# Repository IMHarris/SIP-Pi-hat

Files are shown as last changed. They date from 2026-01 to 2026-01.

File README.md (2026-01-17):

# SIP Pi HAT

Raspberry Pi HAT for the [SIP (Smart Irrigation Program)](https://github.com/Dan-in-CA/SIP) irrigation controller.

## Features

- Designed to interface with SIP irrigation controller on Raspberry Pi
- Outputs for relay control of up to 16 stations with 74HC595 output header for more
- XAIO ESP32C3 module for flow sensor monitoring with inputs for hall flow sensor. Designed to work with the flow plugin
- Communicates flow sensor data to Pi via UART
- 5v I2c headers. Great for LCD plugin.

## Hardware

This project contains KiCad 7+ design files:
- `SIP_Hat.kicad_sch` - Schematic
- `SIP_Hat.kicad_pcb` - PCB layout
- `SIP_Hat.kicad_pro` - Project file
- `Gerber/` - Manufacturing files

## Firmware

The ESP32C3 firmware is available in the companion repository: [flow-sensor-esp32](https://github.com/IMHarris/flow-sensor-esp32)

## Bill of Materials

See `SIP_Hat.csv` for the complete BOM.

## Related Projects

- [SIP Irrigation Controller](https://github.com/Dan-in-CA/SIP)
- [SIP Plugins](https://github.com/Dan-in-CA/sip_plugins)
- [ESP32C3 Flow Sensor Firmware](https://github.com/IMHarris/flow-sensor-esp32)

## License

This hardware design is licensed under [CC BY-SA 4.0](http://creativecommons.org/licenses/by-sa/4.0/).

You are free to share and adapt this work, provided you give appropriate credit and distribute your contributions under the same license.

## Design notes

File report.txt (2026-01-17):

Plotted to '/Users/ianharris/Tech Projects/KiCad SPI Hat/SIP_Hat/Gerber/SIP_Hat-F_Cu.gbr'.
Plotted to '/Users/ianharris/Tech Projects/KiCad SPI Hat/SIP_Hat/Gerber/SIP_Hat-B_Cu.gbr'.
Plotted to '/Users/ianharris/Tech Projects/KiCad SPI Hat/SIP_Hat/Gerber/SIP_Hat-F_Paste.gbr'.
Plotted to '/Users/ianharris/Tech Projects/KiCad SPI Hat/SIP_Hat/Gerber/SIP_Hat-B_Paste.gbr'.
Plotted to '/Users/ianharris/Tech Projects/KiCad SPI Hat/SIP_Hat/Gerber/SIP_Hat-F_Silkscreen.gbr'.
Plotted to '/Users/ianharris/Tech Projects/KiCad SPI Hat/SIP_Hat/Gerber/SIP_Hat-B_Silkscreen.gbr'.
Plotted to '/Users/ianharris/Tech Projects/KiCad SPI Hat/SIP_Hat/Gerber/SIP_Hat-F_Mask.gbr'.
Plotted to '/Users/ianharris/Tech Projects/KiCad SPI Hat/SIP_Hat/Gerber/SIP_Hat-B_Mask.gbr'.
Plotted to '/Users/ianharris/Tech Projects/KiCad SPI Hat/SIP_Hat/Gerber/SIP_Hat-Edge_Cuts.gbr'.
Created Gerber job file '/Users/ianharris/Tech Projects/KiCad SPI Hat/SIP_Hat/Gerber/SIP_Hat-job.gbrjob'.
Info: Done.
Info: Done.

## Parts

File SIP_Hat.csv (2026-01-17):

Reference | Qty | Value | DNP | Exclude from BOM | Exclude from Board | Footprint | Datasheet
5v_in1 | 1 | 10164359-00011LF |  |  |  | 10164359-00011LF:AMPHENOL_10164359-00011LF
C1,C2,C7 | 3 | 0.1µF |  |  |  | Capacitor_SMD:C_0805_2012Metric_Pad1.18x1.45mm_HandSolder | ~
C5,C6,C27 | 3 | 10µF |  |  |  | Capacitor_SMD:C_1206_3216Metric_Pad1.33x1.80mm_HandSolder | https://www.digikey.com/en/products/detail/samsung-electro-mechanics/CL21A106KPFNNNE/3886710,~
D1,D2 | 2 | LED |  |  |  | PCM_LED_SMD_Handsoldering_AKL:LED_1206_3216Metric_Pad1.42x1.75mm | ~
H1,H2,H3,H4 | 4 | MountingHole |  | Excluded from BOM |  | MountingHole:MountingHole_2.7mm_M2.5_ISO14580 | ~
J1 | 1 | Raspberry Pi Header |  |  |  | Connector_PinHeader_2.54mm:PinHeader_2x20_P2.54mm_Vertical | ~
J2 | 1 | Relay terminal 1 |  |  |  | Ians_Parts:PHOENIX_1990083 | ~
J3 | 1 | Relay terminal 2 |  |  |  | Ians_Parts:PHOENIX_1990083 | ~
J4 | 1 | I2C 5V 1 |  |  |  | Connector_PinHeader_2.54mm:PinHeader_1x04_P2.54mm_Vertical | ~
J5 | 1 | I2C 5V 2 |  |  |  | Connector_PinHeader_2.54mm:PinHeader_1x04_P2.54mm_Vertical | ~
J6 | 1 | To Flow Sensor |  |  |  | Ians_Parts:PHOENIX_1729131 | ~
J7 | 1 | Conn_01x06_Pin |  |  |  | Connector_PinHeader_2.54mm:PinHeader_1x06_P2.54mm_Vertical | ~
J22 | 1 | Relay terminal 1 |  |  |  | Connector_Molex:Molex_SL_171971-0010_1x10_P2.54mm_Vertical | ~
J23 | 1 | Relay terminal 2 |  |  |  | Connector_Molex:Molex_SL_171971-0010_1x10_P2.54mm_Vertical | ~
Q1,Q2 | 2 | BSS138 |  |  |  | PCM_Package_TO_SOT_SMD_AKL:SOT-23 | https://www.tme.eu/Document/2b32cdd3c66afedbcd628e73d93ae817/BSS138-7-F.pdf
R1,R9,R10,R11,R12 | 5 | 10k |  |  |  | Resistor_SMD:R_1206_3216Metric_Pad1.30x1.75mm_HandSolder | ~
R3 | 1 | 1.5k |  |  |  | Resistor_SMD:R_1206_3216Metric_Pad1.30x1.75mm_HandSolder | ~
R4,R5 | 2 | 5.1k |  |  |  | Resistor_SMD:R_1206_3216Metric_Pad1.30x1.75mm_HandSolder | ~
R6 | 1 | 470 |  |  |  | Resistor_SMD:R_1206_3216Metric_Pad1.30x1.75mm_HandSolder | ~
SW1 | 1 | SW_Slide_DPDT |  |  |  | Ians_Parts:DPDT Slide switch - CL-SB-22C-02 | ~
U1,U2 | 2 | 74HC595 |  |  |  | Package_DIP:DIP-16_W7.62mm_Socket | http://www.ti.com/lit/ds/symlink/sn74hc595.pdf
U3 | 1 | 113991054 |  |  |  | 113991054:MODULE_113991054 | https://mm.digikey.com/Volume0/opasdata/d220001/medias/docus/6209/Seeed%20113991054.pdf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..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

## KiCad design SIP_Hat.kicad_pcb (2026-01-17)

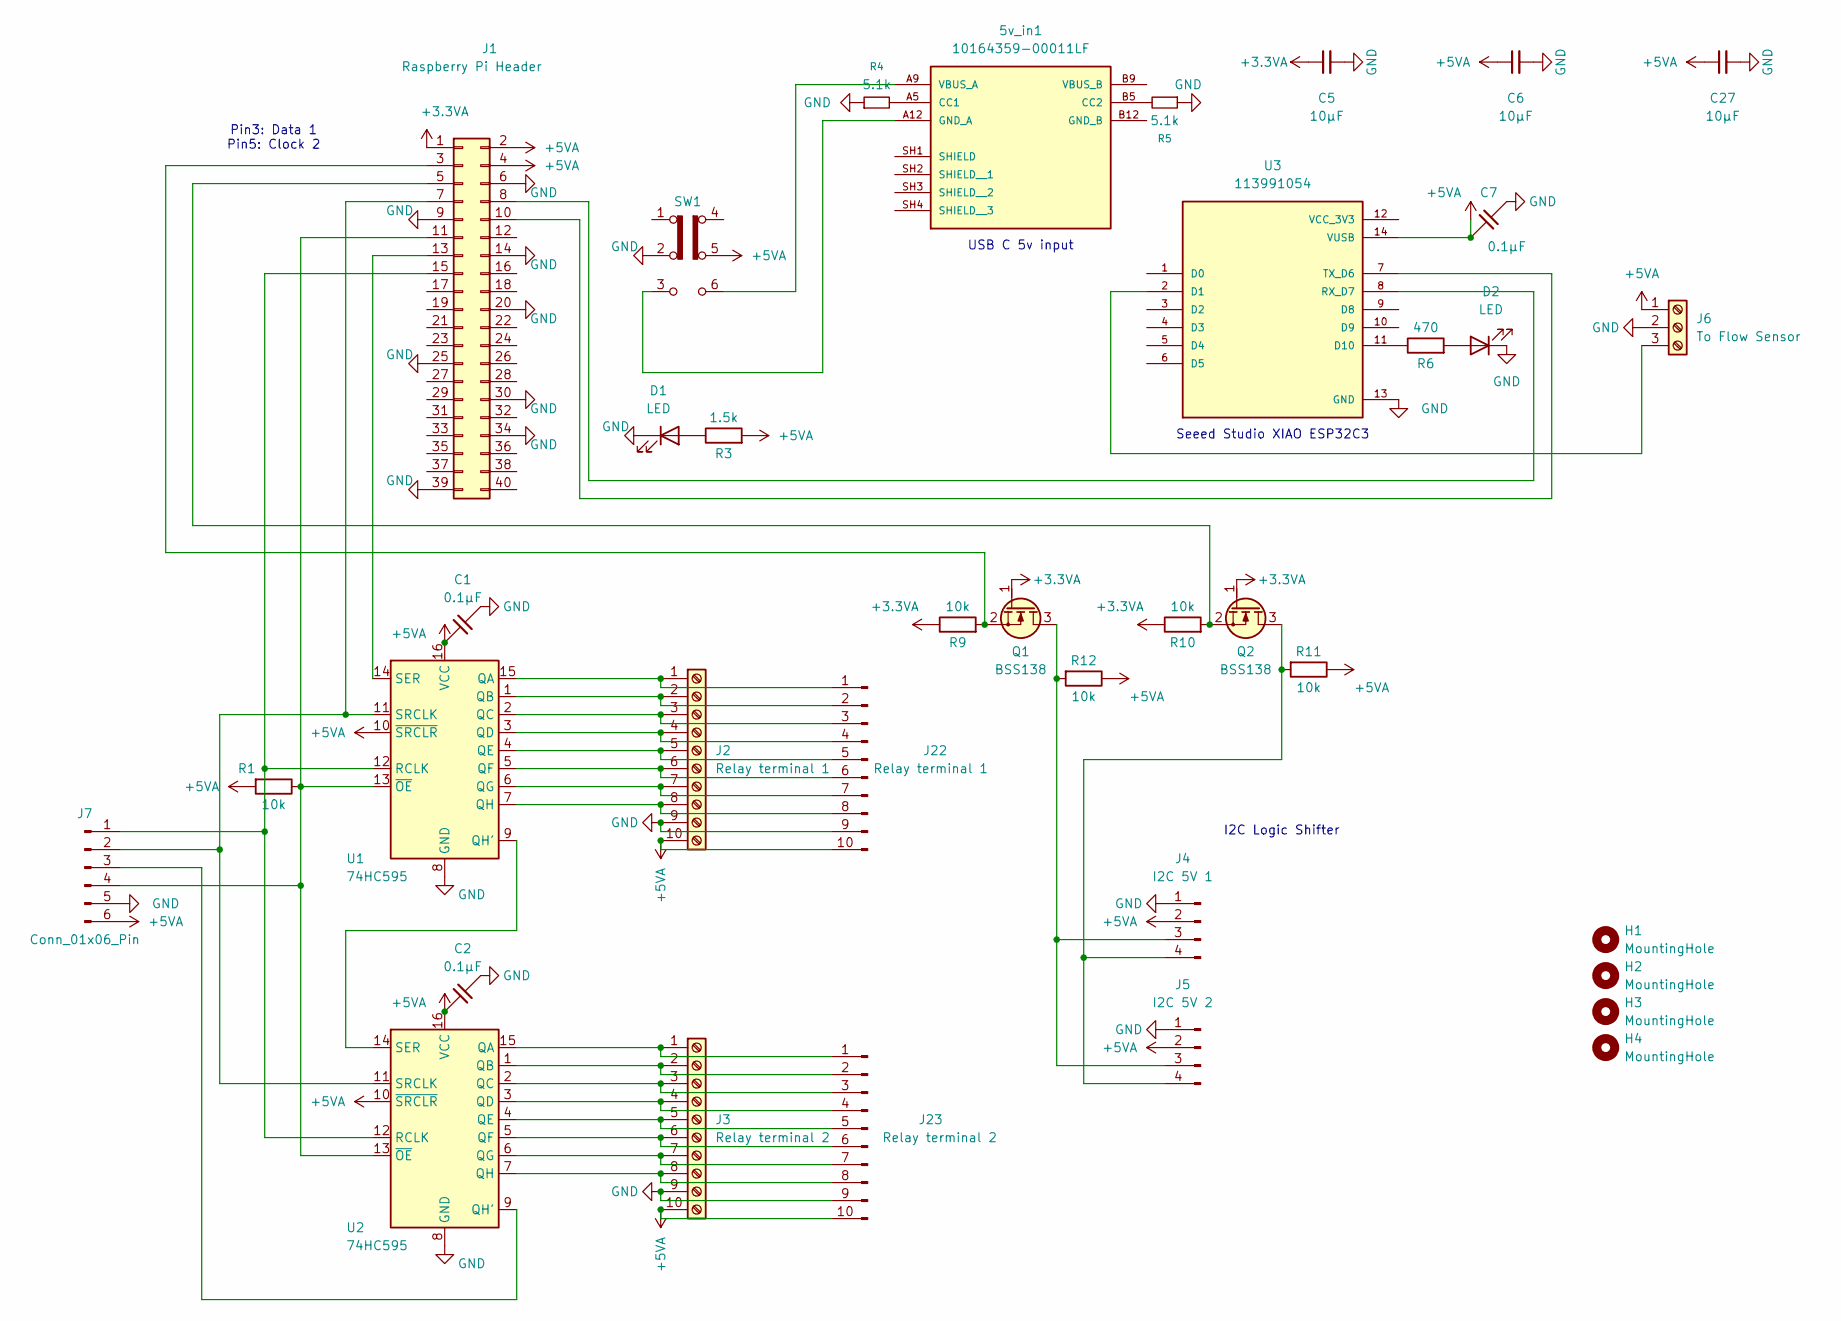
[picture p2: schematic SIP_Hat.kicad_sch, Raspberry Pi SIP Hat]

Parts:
5v_in1: 10164359-00011LF; AMPHENOL_10164359-00011LF; PARTREV A
C1, C2, C7: 0.1µF; C_0805_2012Metric_Pad1.18x1.45mm_HandSolder
C5, C6, C27: 10µF; C_1206_3216Metric_Pad1.33x1.80mm_HandSolder
D1, D2: LED; LED_1206_3216Metric_Pad1.42x1.75mm
H1, H2, H3, H4: MountingHole; MountingHole_2.7mm_M2.5_ISO14580
J1: Raspberry Pi Header; PinHeader_2x20_P2.54mm_Vertical
J2: Relay terminal 1; PHOENIX_1990083
J3: Relay terminal 2; PHOENIX_1990083
J4: I2C 5V 1; PinHeader_1x04_P2.54mm_Vertical
J5: I2C 5V 2; PinHeader_1x04_P2.54mm_Vertical
J6: To Flow Sensor; PHOENIX_1729131
J7: Conn_01x06_Pin; PinHeader_1x06_P2.54mm_Vertical
J22: Relay terminal 1; Molex_SL_171971-0010_1x10_P2.54mm_Vertical
J23: Relay terminal 2; Molex_SL_171971-0010_1x10_P2.54mm_Vertical
Q1, Q2: BSS138; SOT-23
R1, R9, R10, R11, R12: 10k; R_1206_3216Metric_Pad1.30x1.75mm_HandSolder
R3: 1.5k; R_1206_3216Metric_Pad1.30x1.75mm_HandSolder
R4, R5: 5.1k; R_1206_3216Metric_Pad1.30x1.75mm_HandSolder
R6: 470; R_1206_3216Metric_Pad1.30x1.75mm_HandSolder
SW1: SW_Slide_DPDT; DPDT Slide switch - CL-SB-22C-02
U1, U2: 74HC595; DIP-16_W7.62mm_Socket
U3: 113991054; MODULE_113991054; PARTREV 23/05/2022

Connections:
+3.3VA: C5.1, J1.1, Q1.1 (G), Q2.1 (G), R9.1, R10.1
+5VA: C1.2, C2.2, C6.1, C7.2, C27.1, J1.2, J1.4, J2.10, J3.10, J4.2, J5.2, J6.1, J7.6, J22.10, J23.10, R1.2, R3.2, R11.1, R12.1, SW1.5 (B), U1.10 (~SRCLR), U1.16 (VCC), U2.10 (~SRCLR), U2.16 (VCC), U3.14 (VUSB)
GND: C1.1, C2.1, C5.2, C6.2, C7.1, C27.2, D1.1 (K), D2.1 (K), J1.6, J1.9, J1.14, J1.20, J1.25, J1.30, J1.34, J1.39, J2.9, J3.9, J4.1, J5.1, J6.2, J7.5, J22.9, J23.9, R4.1, R5.1, SW1.2 (B), U1.8 (GND), U2.8 (GND), U3.13 (GND)
unnamed: 5v_in1.A5 (CC1), R4.2
unnamed: 5v_in1.B5 (CC2), R5.2
unnamed: 5v_in1.A12 (GND_A), SW1.3 (C)
unnamed: 5v_in1.A9 (VBUS_A), SW1.6 (A)
unnamed: D1.2 (A), R3.1
unnamed: D2.2 (A), R6.2
unnamed: J1.3, Q1.2 (S), R9.2
unnamed: J1.5, Q2.2 (S), R10.2
unnamed: J1.7, J7.2, U1.11 (SRCLK), U2.11 (SRCLK)
unnamed: J1.8, U3.8 (RX_D7)
unnamed: J1.10, U3.7 (TX_D6)
unnamed: J1.11, J7.4, R1.1, U1.13 (~OE), U2.13 (~OE)
unnamed: J1.13, U1.14 (SER)
unnamed: J1.15, J7.1, U1.12 (RCLK), U2.12 (RCLK)
unnamed: J2.1, J22.1, U1.15 (QA)
unnamed: J2.2, J22.2, U1.1 (QB)
unnamed: J2.3, J22.3, U1.2 (QC)
unnamed: J2.4, J22.4, U1.3 (QD)
unnamed: J2.5, J22.5, U1.4 (QE)
unnamed: J2.6, J22.6, U1.5 (QF)
unnamed: J2.7, J22.7, U1.6 (QG)
unnamed: J2.8, J22.8, U1.7 (QH)
unnamed: J4.3, J5.3, Q1.3 (D), R12.2
unnamed: J4.4, J5.4, Q2.3 (D), R11.2
unnamed: J6.3, U3.2 (D1)
unnamed: J7.3, U2.9 (QH')
unnamed: J3.1, J23.1, U2.15 (QA)
unnamed: J3.2, J23.2, U2.1 (QB)
unnamed: J3.3, J23.3, U2.2 (QC)
unnamed: J3.4, J23.4, U2.3 (QD)
unnamed: J3.5, J23.5, U2.4 (QE)
unnamed: J3.6, J23.6, U2.5 (QF)
unnamed: J3.7, J23.7, U2.6 (QG)
unnamed: J3.8, J23.8, U2.7 (QH)
unnamed: U1.9 (QH'), U2.14 (SER)
unnamed: R6.1, U3.11 (D10)

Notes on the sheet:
USB C 5v input
I2C Logic Shifter
Seeed Studio XIAO ESP32C3
Pin3: Data 1 Pin5: Clock 2

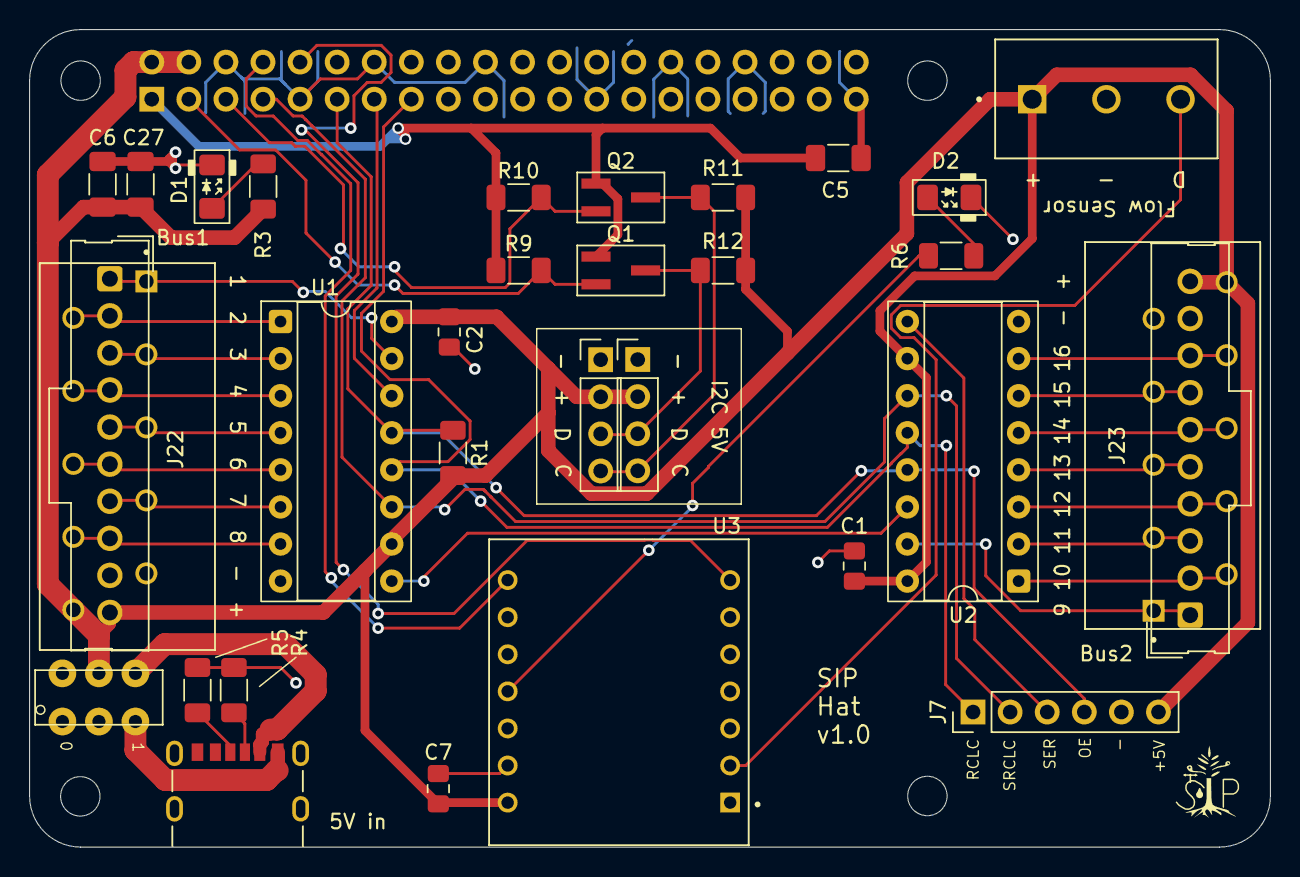
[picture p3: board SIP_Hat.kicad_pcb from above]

Board: 2 copper layers, 85.0 x 56.0 mm, 37 parts (0 on the bottom side), 39 nets.

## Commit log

2025-11-29 Initial commit: SIP Pi HAT hardware design
    - Add KiCad 7 project files for Raspberry Pi HAT
    - Include XAIO ESP32C3 for flow sensor monitoring
    - Add BOM and gerber job file
    - Design interfaces with SIP irrigation controller
    [SPI_Hat.csv, SPI_Hat.kicad_pcb, SPI_Hat.kicad_sch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]
2025-11-29 Update .gitignore to include Gerber files and exclude lock files
2025-11-29 Add Gerber manufacturing files for SIP Pi HAT
    [SPI_Hat-B_Cu.gbr, SPI_Hat-B_Mask.gbr, SPI_Hat-B_Paste.gbr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]
2026-01-17 Rename project from SPI_Hat to SIP_Hat
    - Renamed all SPI_Hat files to SIP_Hat (correct project name)
    - Updated .gitignore to exclude additional KiCad autosave files
    - Added graphics assets and documentation image
    [SIP_Hat-B_Cu.gbr, SIP_Hat-B_Mask.gbr, SIP_Hat-B_Paste.gbr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]
